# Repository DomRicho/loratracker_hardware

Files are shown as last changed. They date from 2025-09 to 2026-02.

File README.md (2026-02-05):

# LoRa Tracker HAT+

This board was developed for my engineering honours project, exploring how LoRa—a low-power, long-range wireless technology—could improve animal tracking. 
Now LoRa is already well established in this field. However, is removing the need for GNSS by localising using the LoRa packets possible? 
This could simplify devices, save battery, and reduce interference with wildlife behaviour, especially for small or sensitive species 
like wild bilbies.

The project investigates two localisation methods: **RSSI** and **Time-Difference of Arrival (TDoA)**.

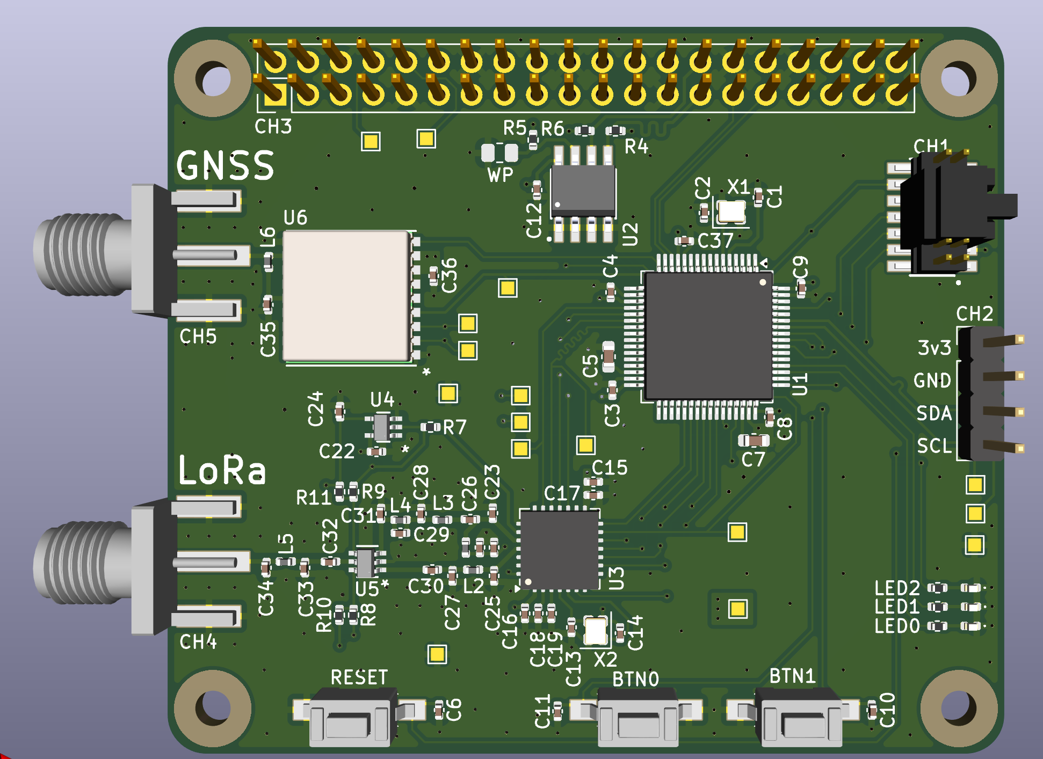
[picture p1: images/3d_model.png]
3D Model


The HAT+ is a custom Raspberry Pi board featuring an STM32H7, GNSS module, LoRa modem, and I2C environmental sensor. 
Three boards act as anchors to trilaterate LoRa packet sources. To handle packets moving at the speed of light, the
anchors are synchronised via GPS pulse-per-second signals, keeping jitter under 20 ns.

## Issues

- CADDetected on the SX1272 couldn’t reliably timestamp preambles; switched to using the **ValidHeader** flag instead.  
- DIO4 trace was cut, and DIO3 was rerouted to the STM32H7 input capture pin.  
- Standard crystals drift roughly 20 µs, translating to tens of km of error. Achieving nanosecond-level timing 
requires expensive oven-controlled crystals (~$450 for three), compared to ~$0.60 for standard ones. Lesson learned

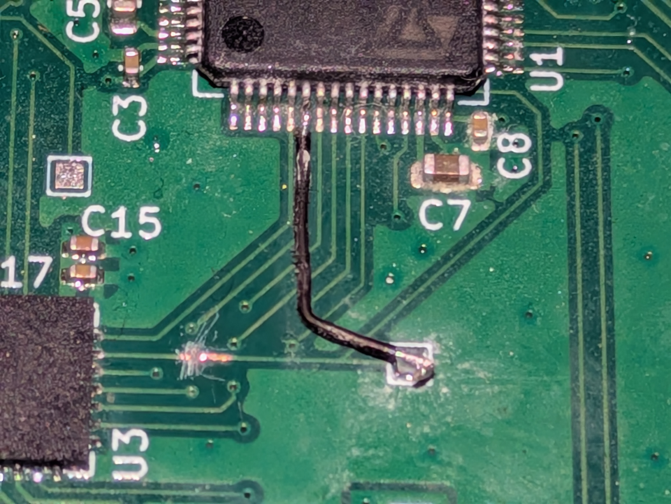
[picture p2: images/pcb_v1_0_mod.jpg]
PCB v1.0 Mod


## Future Plans
- Battery power  
- Solar charging

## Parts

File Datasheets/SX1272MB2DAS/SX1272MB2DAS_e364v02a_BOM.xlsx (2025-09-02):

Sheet: SX1272MB2DAS - BOM
 |  |  | SX1272MB2DAS - BOM |  |  | BOM # V1a
 |  |  |  |  |  | SCH # e364v02a
 |  |  | 2023-08-17 | EMr | Version e364V02a - 868MHz and 915MHz | PCB # e364v02a
RefDes | MPN | Geom | Value | Qty | Description | Manufacturer
IC
U1 | SX1272IMLTRT | TQFN-28 6x6mm | SX1272 | 1 | 860MHz to 1020MHz Low Power Long Range Transceiver | Semtech
U2 | PE4259 | SC-70-6 | - | 1 | PE4259 - 10MHz to 3GHz SPDT RF Switch | Peregrine Semi
U3 | NC7SZ04P5X | SC-70-5 | - | 1 | NC7SZ04 TinyLogic UHS Inverter | Fairchild Semi
U4 | CRCW06030000Z0EA | 0603 | 0R | 1 | Thick Film Resistor ±5%, 1/10W (No SAW filter populated) | Vishay/Dale
Resistors
R1 | CRCW04023K30JNED | 0402 | 3.3k | 1 | Thick Film Resistor ±5%, 1/16W | Vishay/Dale
R2 | CRCW04023K30JNED | 0402 | 3.3k | 1 | Thick Film Resistor ±5%, 1/16W | Vishay/Dale
R3 | CRCW06030000Z0EA | 0603 | 0R | 1 | Thick Film Resistor ±5%, 1/10W | Vishay/Dale
R4 | EXB-N8V101JX | EXB28V | 100R | 1 | SMD Resistor Array Resistors (4x), ±5%, 31mW | Panasonic - ECG
R5 | EXB-N8V101JX | EXB28V | 100R | 1 | SMD Resistor Array Resistors (4x), ±5%, 31mW | Panasonic - ECG
R6 | CRCW06030000Z0EA | 0603 | 0R | 1 | Thick Film Resistor ±5%, 1/10W | Vishay/Dale
R7 | CRCW0402100RJNED | 0402 | 100R | 1 | Thick Film Resistor ±5%, 1/16W | Vishay/Dale
R11 | CRCW04021K00JNED | 0402 | 1k | 1 | Thick Film Resistor ±5%, 1/16W | Vishay/Dale
R14 | CRCW0402100RJNED | 0402 | 100R | 1 | Thick Film Resistor ±5%, 1/16W | Vishay/Dale
Capacitors
C1 | GJM1555C1H150JB01D | 0402 | 15pF | 1 | Multilayer ceramic capacitors C0G ±5%, 50V | Murata
C2 | GJM1555C1H150JB01D | 0402 | 15pF | 1 | Multilayer ceramic capacitors C0G ±5%, 50V | Murata
C3 | GRM155R71H104KE14D | 0402 | 100nF | 1 | Multilayer ceramic capacitors X7R ±10%, 50V | Murata
C4 | GRM155R71H104KE14D | 0402 | 100nF | 1 | Multilayer ceramic capacitors X7R ±10%, 50V | Murata
C5 | GRM155R71H104KE14D | 0402 | 100nF | 1 | Multilayer ceramic capacitors X7R ±10%, 50V | Murata
C6 | GRM155R61C105KA12D | 0402 (0603) | 1uF | 1 | Multilayer ceramic capacitors X5R ±10%, 16V | Murata
C7 | GRM155R71H103KA88D | 0402 | 10nF | 1 | Multilayer ceramic capacitors X7R ±10%, 50V | Murata
C8 | GJM1555C1H470JB01D | 0402 | 47pF | 1 | Multilayer ceramic capacitors C0G ±5%, 50V | Murata
C9 | GJM1555C1H330JB01D | 0402 | 33pF | 1 | Multilayer ceramic capacitors C0G ±5%, 50V | Murata
C10 | GJM1555C1H1R5BB01D | 0402 | 1.5pF | 1 | Multilayer ceramic capacitors C0G ±0.1pF, 50V | Murata
C11 | GJM1555C1H4R7CB01D | 0402 | 4.7pF | 1 | Multilayer ceramic capacitors C0G ±0.25pF, 50V | Murata
C12 | GJM1555C1H1R2BB01D | 0402 | 1.2pF | 1 | Multilayer ceramic capacitors C0G ±0.1pF, 50V | Murata
C13 | GJM1555C1H1R8BB01D | 0402 | 1.8pF | 1 | Multilayer ceramic capacitors C0G ±0.1pF, 50V | Murata
C15 | GJM1555C1H3R3BB01D | 0402 | 3.3pF | 1 | Multilayer ceramic capacitors C0G ±0.1pF, 50V | Murata
C16 | GJM1555C1H470JB01D | 0402 | 47pF | 1 | Multilayer ceramic capacitors C0G ±5%, 50V | Murata
C17 | GRM155R72A102KA01D | 0402 | 1nF | 1 | Multilayer ceramic capacitors X7R ±10%, 100V | Murata
C18 | GJM1555C1H470JB01D | 0402 | 47pF | 1 | Multilayer ceramic capacitors C0G ±5%, 50V | Murata
C21 | GRM155R71H104KE14D | 0402 | 100nF | 1 | Multilayer ceramic capacitors X7R ±10%, 50V | Murata
C22 | GRM155R72A102KA01D | 0402 | 1nF | 1 | Multilayer ceramic capacitors X7R ±10%, 100V | Murata
C23 | GRM188R60J226MEA0D | 0603 (0805) | 22uF | 1 | Multilayer ceramic capacitors X5R ±20%, 6.3V | Murata
C24 | GRM155R61C105KA12D | 0402 (0603) | 1uF | 1 | Multilayer ceramic capacitors X5R ±10%, 16V | Murata
C25 | GRM155R61C105KA12D | 0402 (0603) | 1uF | 1 | Multilayer ceramic capacitors X5R ±10%, 16V | Murata
C26 | GRM155R71H104KE14D | 0402 | 100nF | 1 | Multilayer ceramic capacitors X7R ±10%, 50V | Murata
C27 | GRM155R71H104KE14D | 0402 | 100nF | 1 | Multilayer ceramic capacitors X7R ±10%, 50V | Murata
Inductors & Ferrites
L1 | LQW15AN33NJ00D | 0402 | 33nH | 1 | Wirewound Inductor ±5% | Murata
L3 | LQG15HS10NJ02D | 0402 | 10nH | 1 | Multilayer Inductor ±5% | Murata
L4 | LQG15HS6N2S02D | 0402 | 6.2nH | 1 | Multilayer Inductor ±0.3nH | Murata
L5 | LQG15HS10NJ02D | 0402 | 10nH | 1 | Multilayer Inductor ±5% | Murata
L6 | CRCW04020000Z0ED | 0402 | 0R | 1 | Thick Film Resistor ±5%, 1/16W | Vishay/Dale
Crystal (or other referenced vendors)
Q1 | EXS00A-CS06465 | NX2016SA 2.0x1.6mm | 32.000MHz | 1 | Crystal unit NDK; Tol. ±10ppm, Cload=10pF, G-Senstivity=2ppb/G max | NDK
or | FTR5123-B0 | QESM09 2.0x1.6mm | 32.000MHz | - | Crystal unit Rakon; Tol. ±10ppm, Cload=10pF, G-Senstivity=2ppb/G max | Rakon
Connectors and others (or P/N equivalent)
ANT | 142-0711-821 | SMA End Launch | 50 Ohms | 1 | SMA End launch jack receptacle for PCB mount | Emerson Network Power
J1 | 68000-108HLF | Header 1x8 | 8 pins | 1 | 8 Pins - Through hole single row male connector, Bottom side | FCI
J2 | 68000-110HLF | Header 1x10 | 10 pins | 1 | 10 Pins - Through hole single row male connector, Bottom side | FCI
J3 | 68000-108HLF | Header 1x8 | 8 pins | 1 | 8 Pins - Through hole single row male connector, Bottom side | FCI
J4 | 68000-106HLF | Header 1x6 | 6 pins | 1 | 6 Pins - Through hole single row male connector, Bottom side | FCI
ANA_A1 | 1125S-4P | Header 1x4 | 4 pins | 1 | 4 Pins - 2mm pitch - Through hole single row male header connector with lock, Top side | Shenzhen NS-Tech
ANA_A3 | 1125S-4P | Header 1x4 | 4 pins | 1 | 4 Pins - 2mm pitch - Through hole single row male header connector with lock, Top side | Shenzhen NS-Tech
DIO_D6 | 1125S-4P | Header 1x4 | 4 pins | 1 | 4 Pins - 2mm pitch - Through hole single row male header connector with lock, Top side | Shenzhen NS-Tech
DIO_D8 | 1125S-4P | Header 1x4 | 4 pins | 1 | 4 Pins - 2mm pitch - Through hole single row male header connector with lock, Top side | Shenzhen NS-Tech
I2C | 1125S-4P | Header 1x4 | 4 pins | 1 | 4 Pins - 2mm pitch - Through hole single row male header connector with lock, Top side | Shenzhen NS-Tech
UART | 1125S-4P | Header 1x4 | 4 pins | 1 | 4 Pins - 2mm pitch - Through hole single row male header connector with lock, Top side | Shenzhen NS-Tech
Additional or optional components
- | BMIS-205-F | Shield | - | 0 | Standard Surface Mount Shield in two parts with BMIS-205-C cover | Laird Technologies
Remarks: components not listed in the BOM or 0 quantity, are not populated on the module.
It is recommended to use Semtech TVS diode model RClamp2451ZA placed close to the antenna connectors, to protect sensitive RF ports from damage or latch-up due to ESD, EFT, and EOS.
Murata GRM15 Multilayer ceramic capacitors series with values ≤ 47pF were replaced from previous BOM to new GJM15 series, as replacement with same capacitance value, voltage rating and tolerance.
GRM15 series ≤ 47pF are not recommended for new designs according to Murata.

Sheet: Release
 |  | SX1272MB2DAS - BOM |  |  |  | BOM # V1a
 |  |  |  |  |  | SCH # e364v02a
 |  | 2023-08-17 | EMr | Version e364v02a |  | PCB # e364v02a
Release history
Version | Change notes |  |  |  | By
pcb_e364V01a | BOM based on SX1272MB1DAS V1a + added Grove sensors - 14.01.16 |  |  |  | EMr
 | Modifed 32.0MHz crystal 2.0x1.6mm footprint for Q1 |  |  |  | EMr
 | Modifed C2=15pF to center RF frequency using NX2016SA NDK Crystal - 05.02.16 |  |  |  | EMr
pcb_e364V02a | Modied R5 & R13 - changed silkscreen labels |  |  |  | EMr
 | Added BMIS-205-F reference for RF shield in the BOM - not populated - 13.04.16 |  |  |  | EMr
 | Change SX1272MB2DAS Part number on BOM - 27.05.16 |  |  |  | EMr
 | Updated Part Numbers for obsolete capacitors type (value < 100pF) - no change on components values |  |  |  | EMr - 18.10.22
 | Updated Crystal P/N and Update GJM15 Capacitors type |  |  |  | 2023-08-15

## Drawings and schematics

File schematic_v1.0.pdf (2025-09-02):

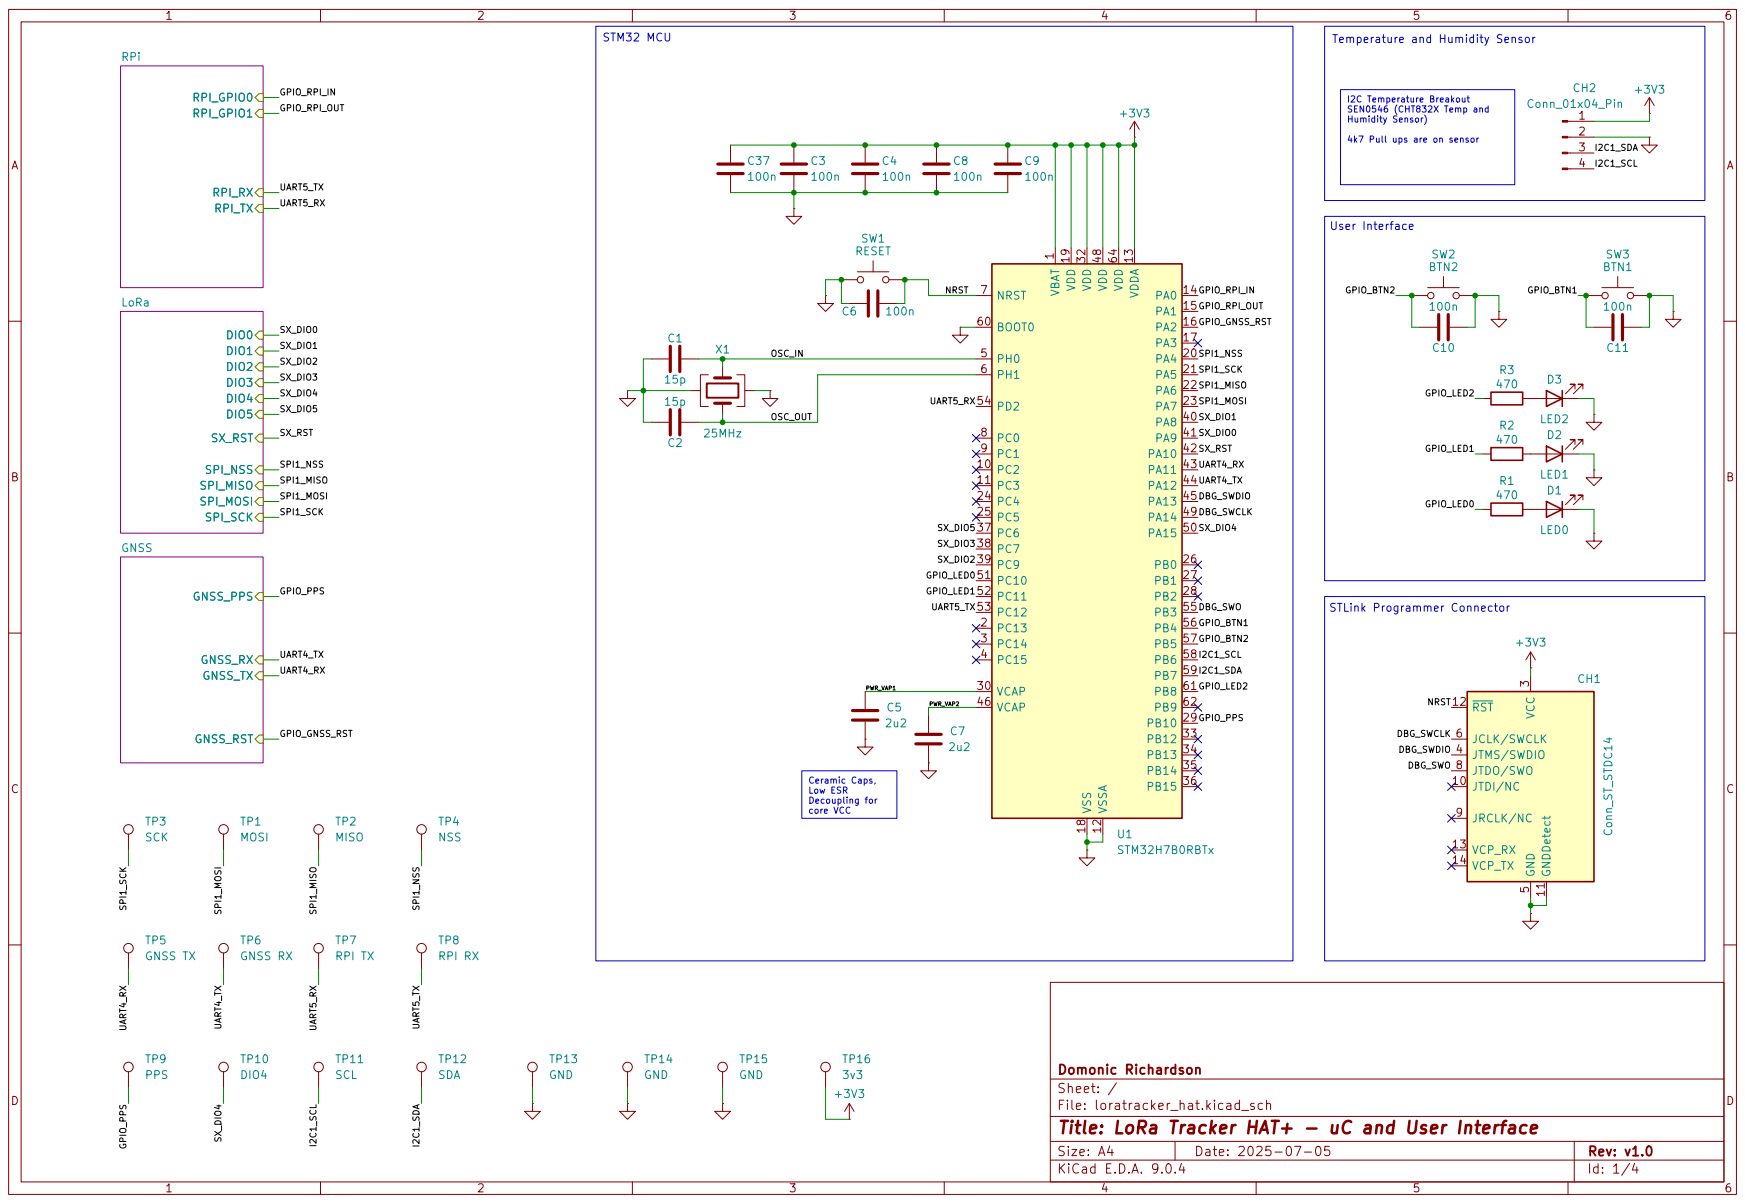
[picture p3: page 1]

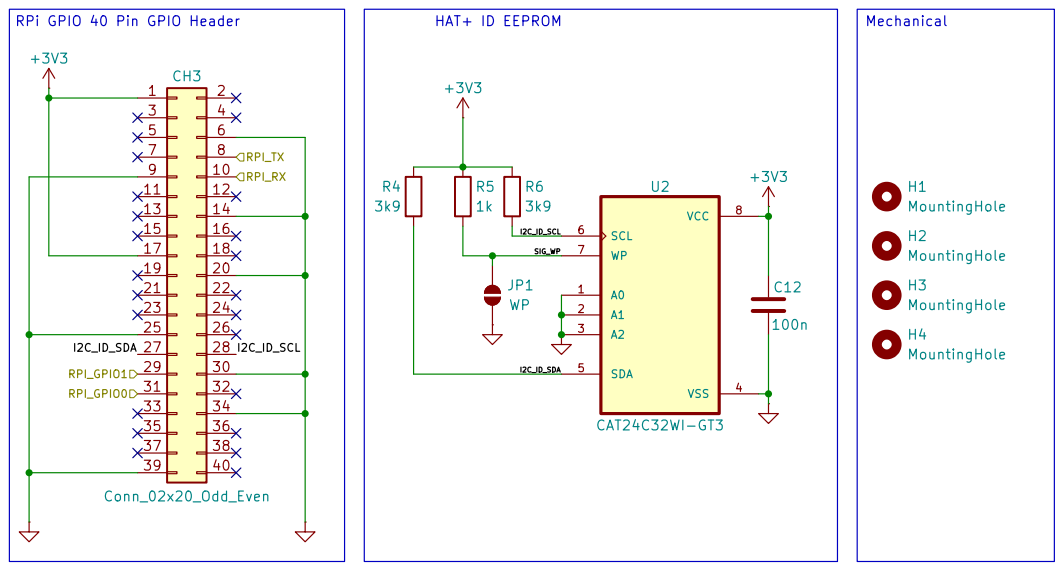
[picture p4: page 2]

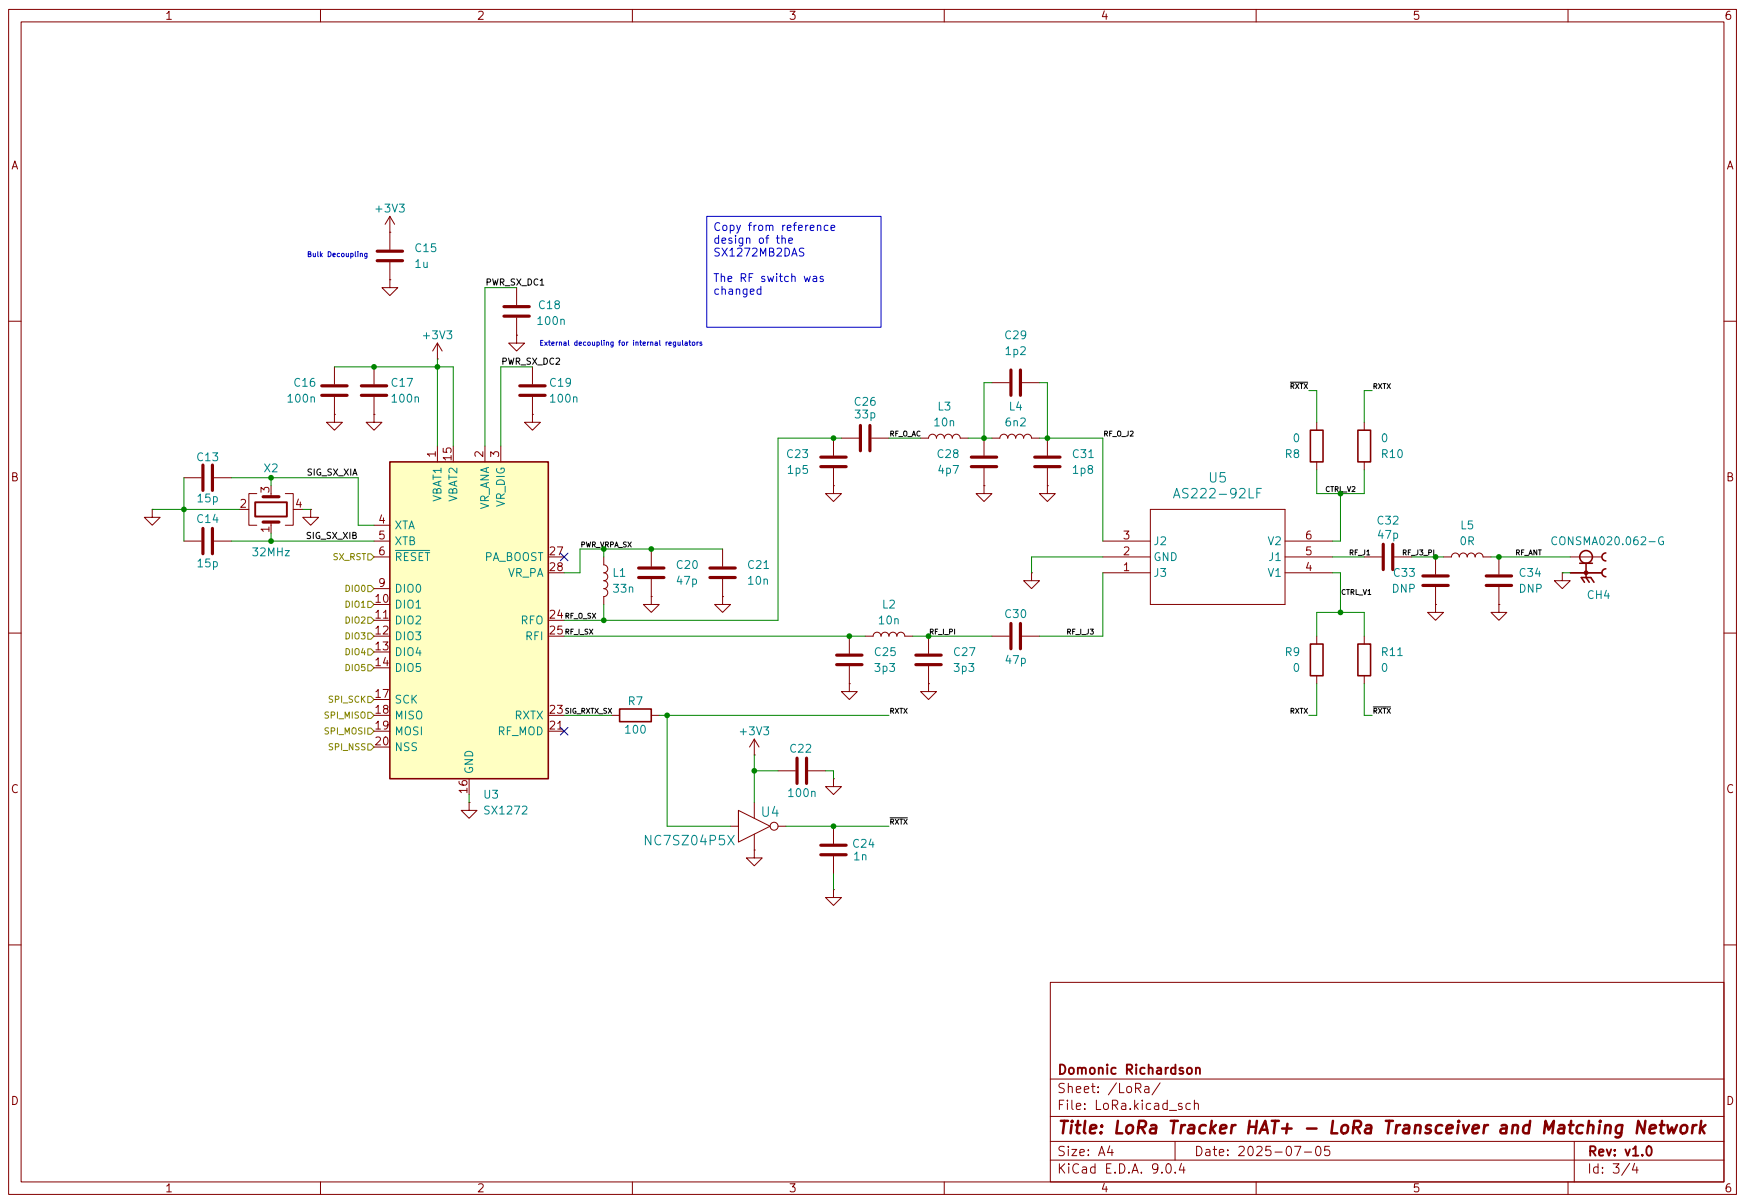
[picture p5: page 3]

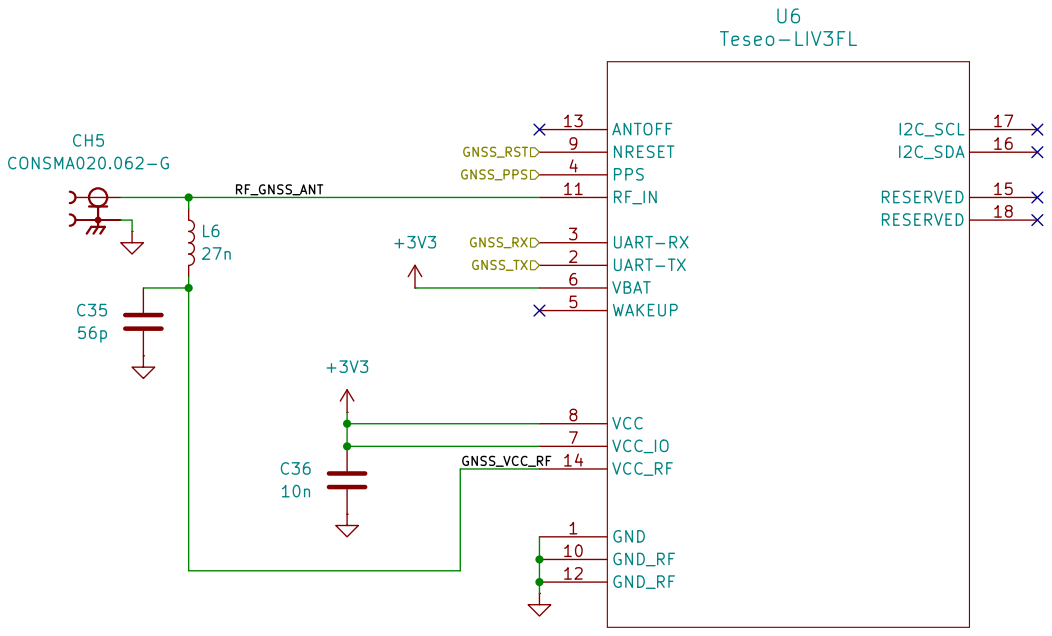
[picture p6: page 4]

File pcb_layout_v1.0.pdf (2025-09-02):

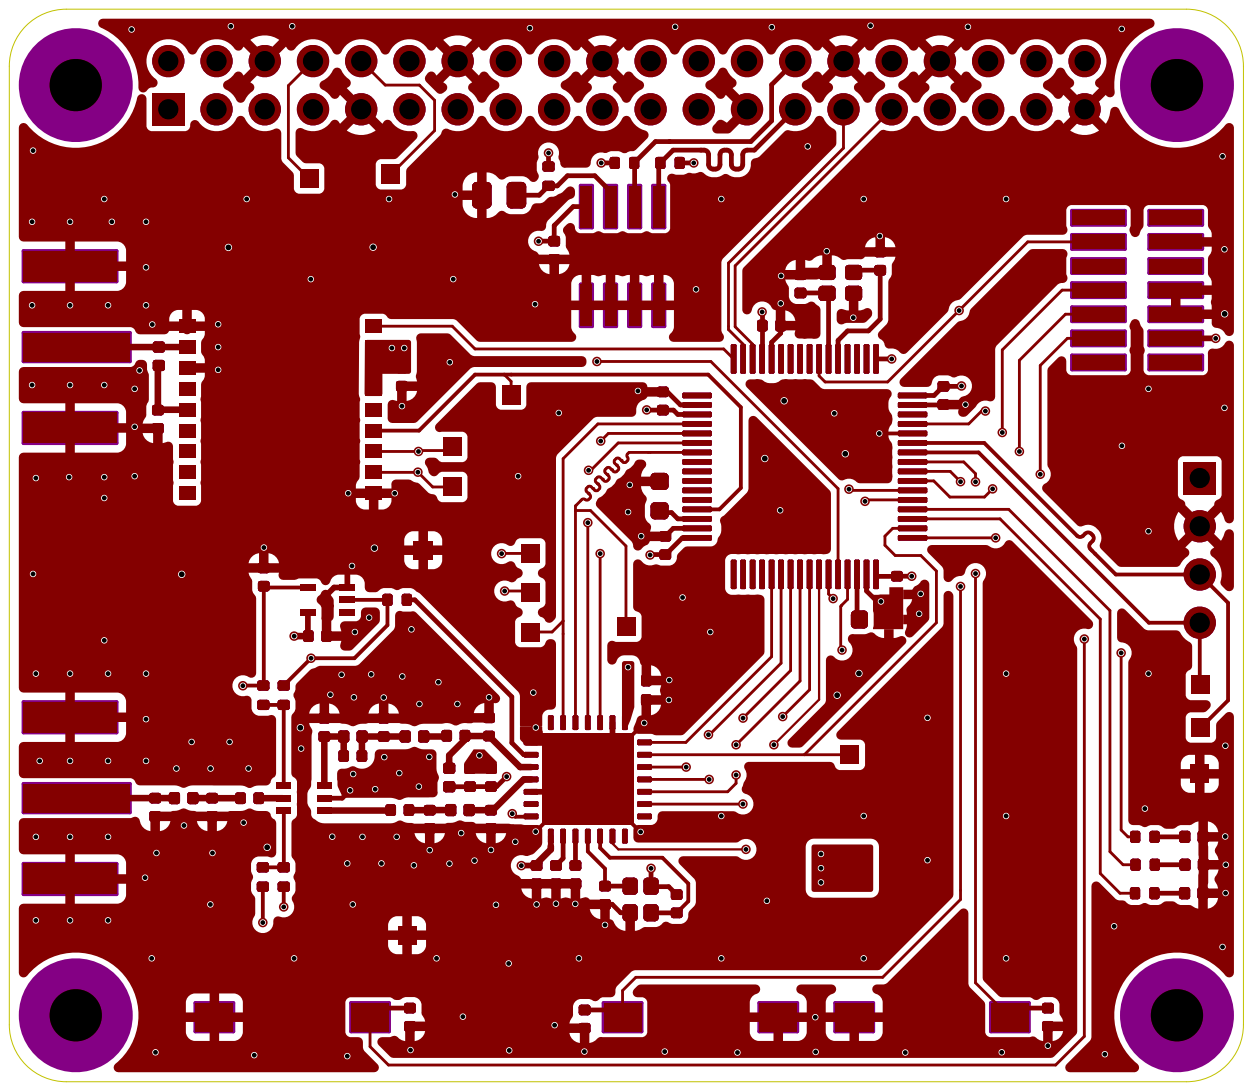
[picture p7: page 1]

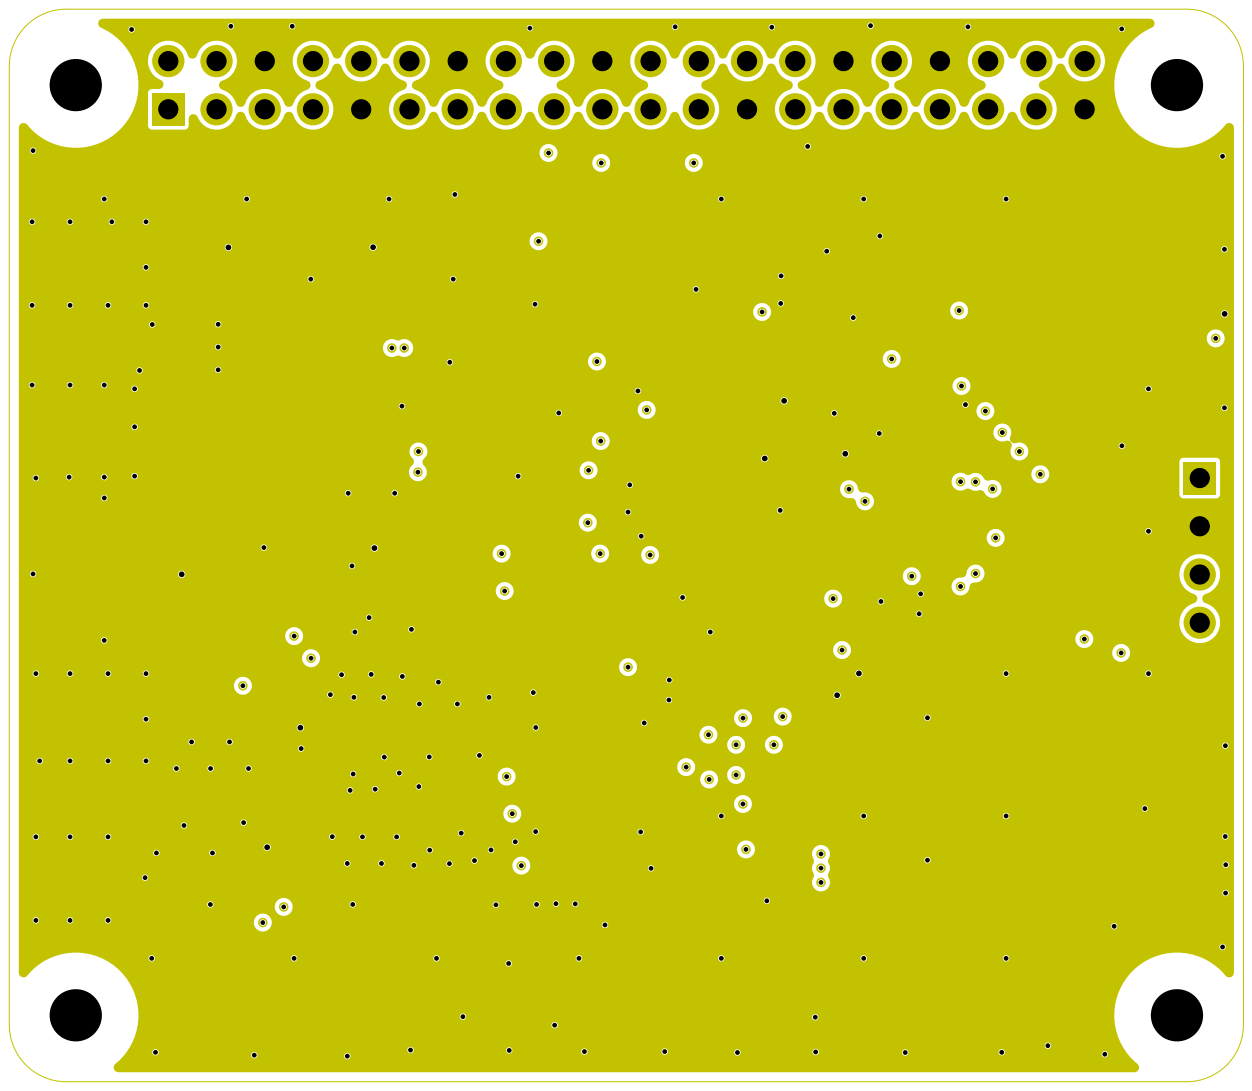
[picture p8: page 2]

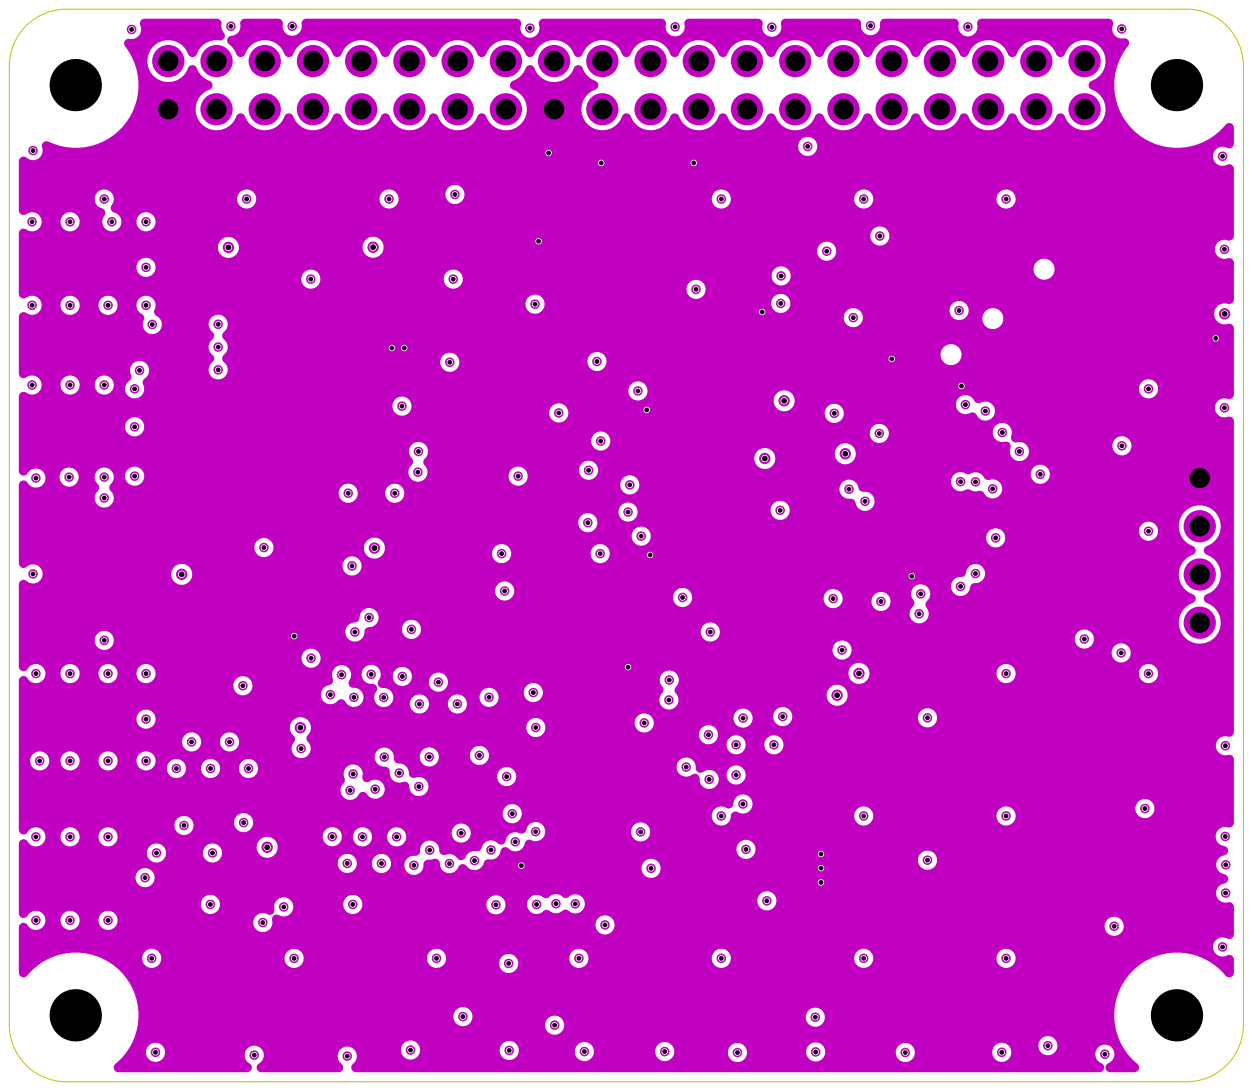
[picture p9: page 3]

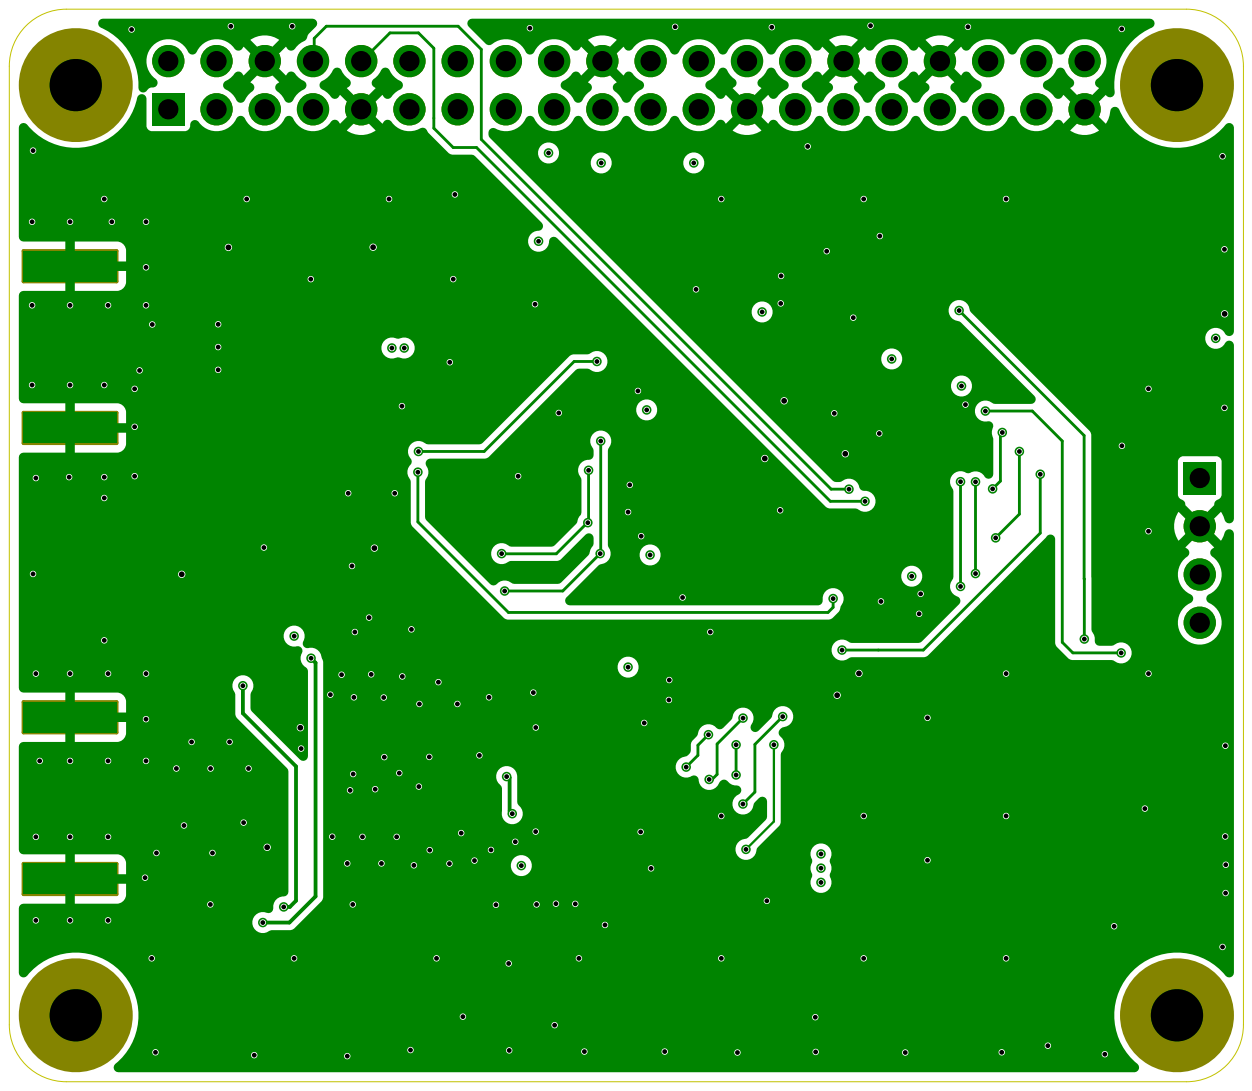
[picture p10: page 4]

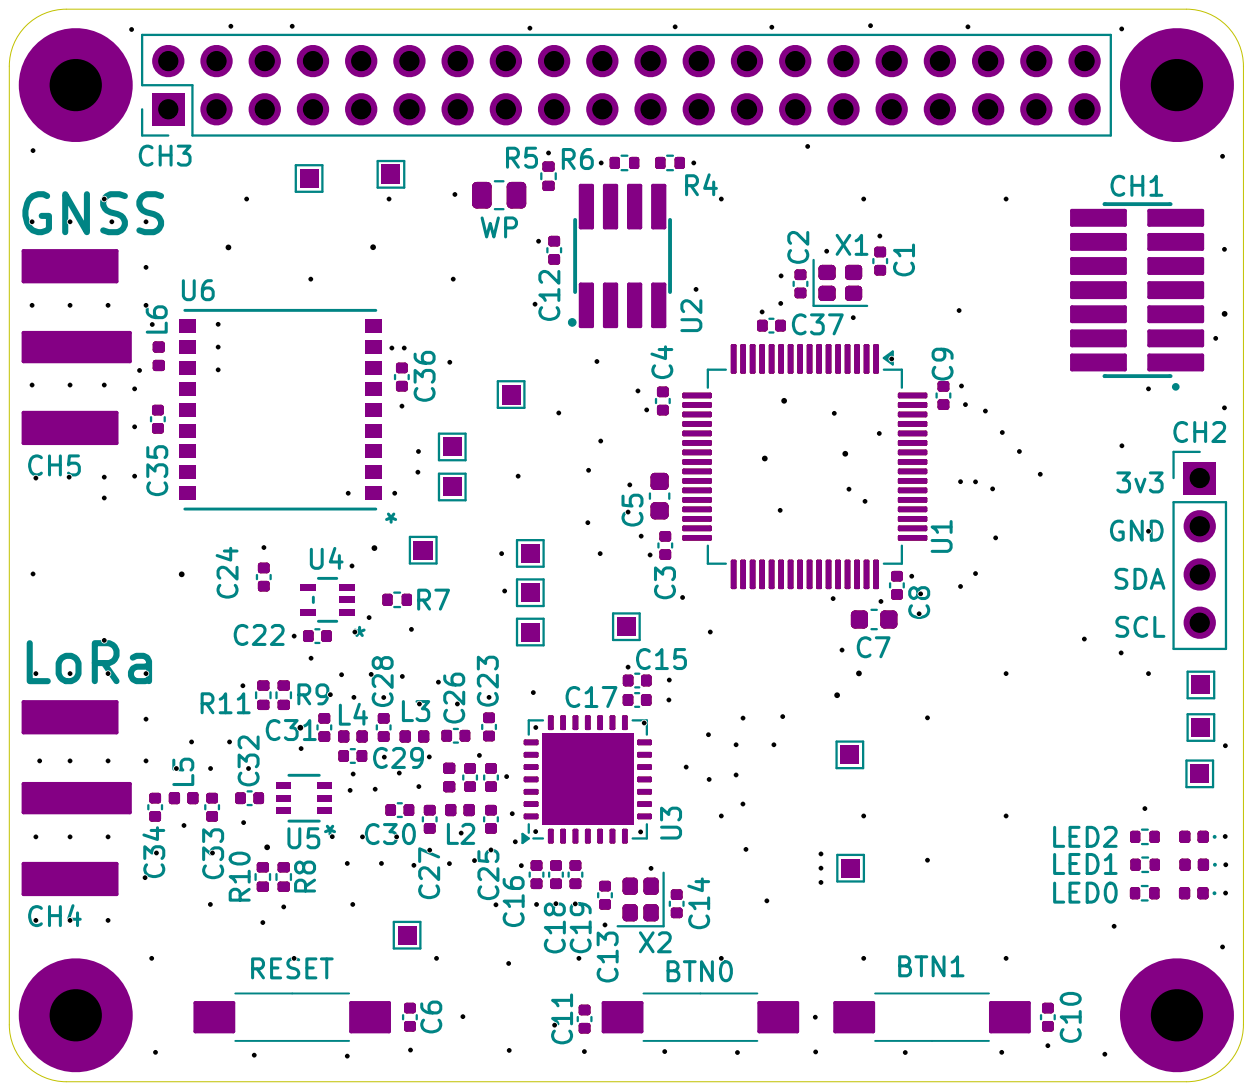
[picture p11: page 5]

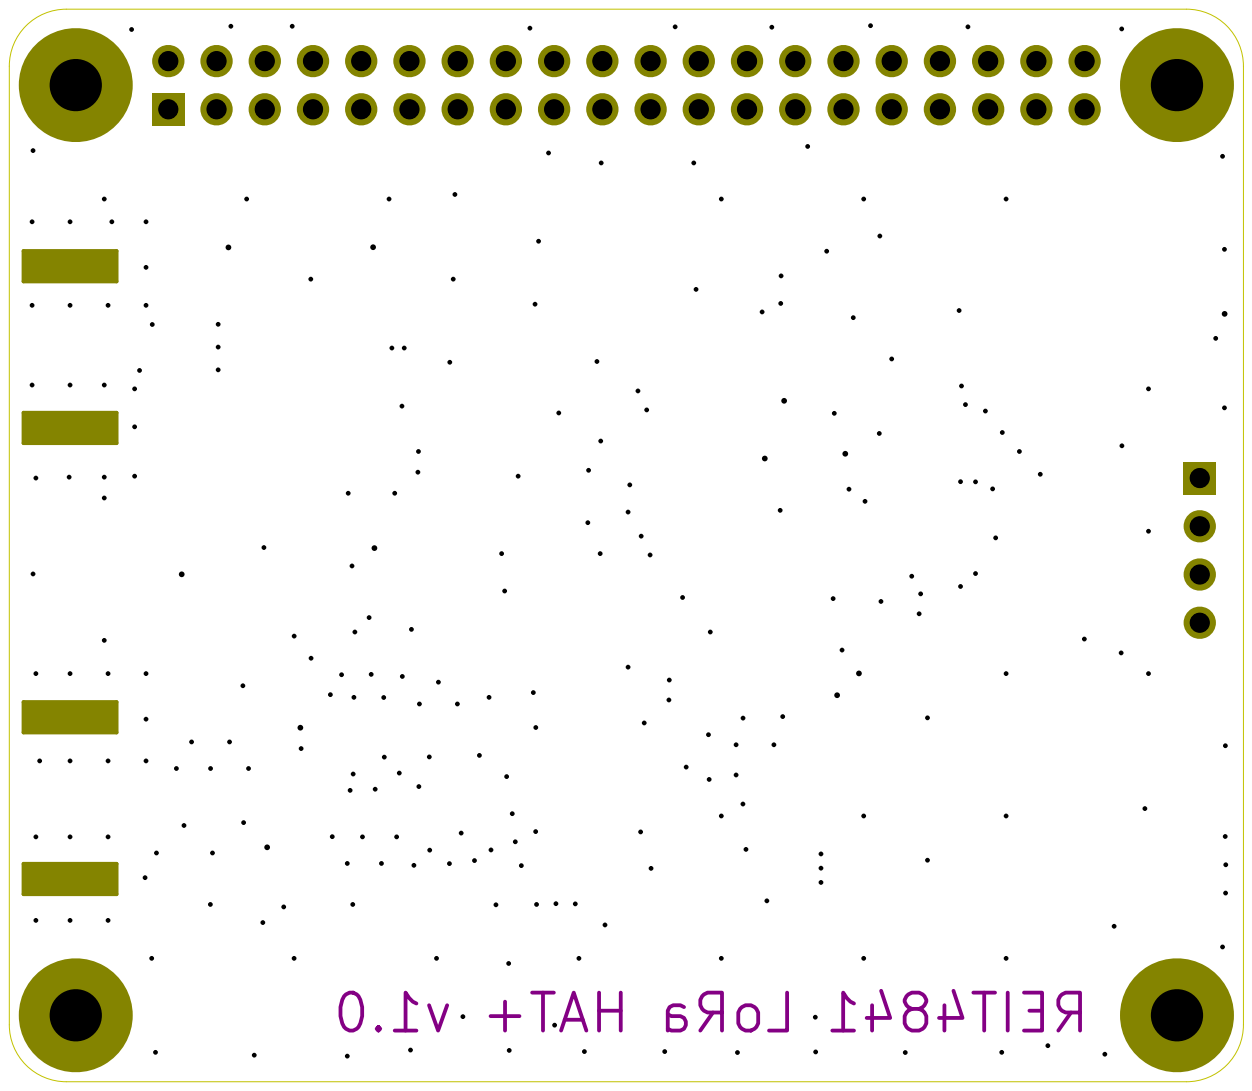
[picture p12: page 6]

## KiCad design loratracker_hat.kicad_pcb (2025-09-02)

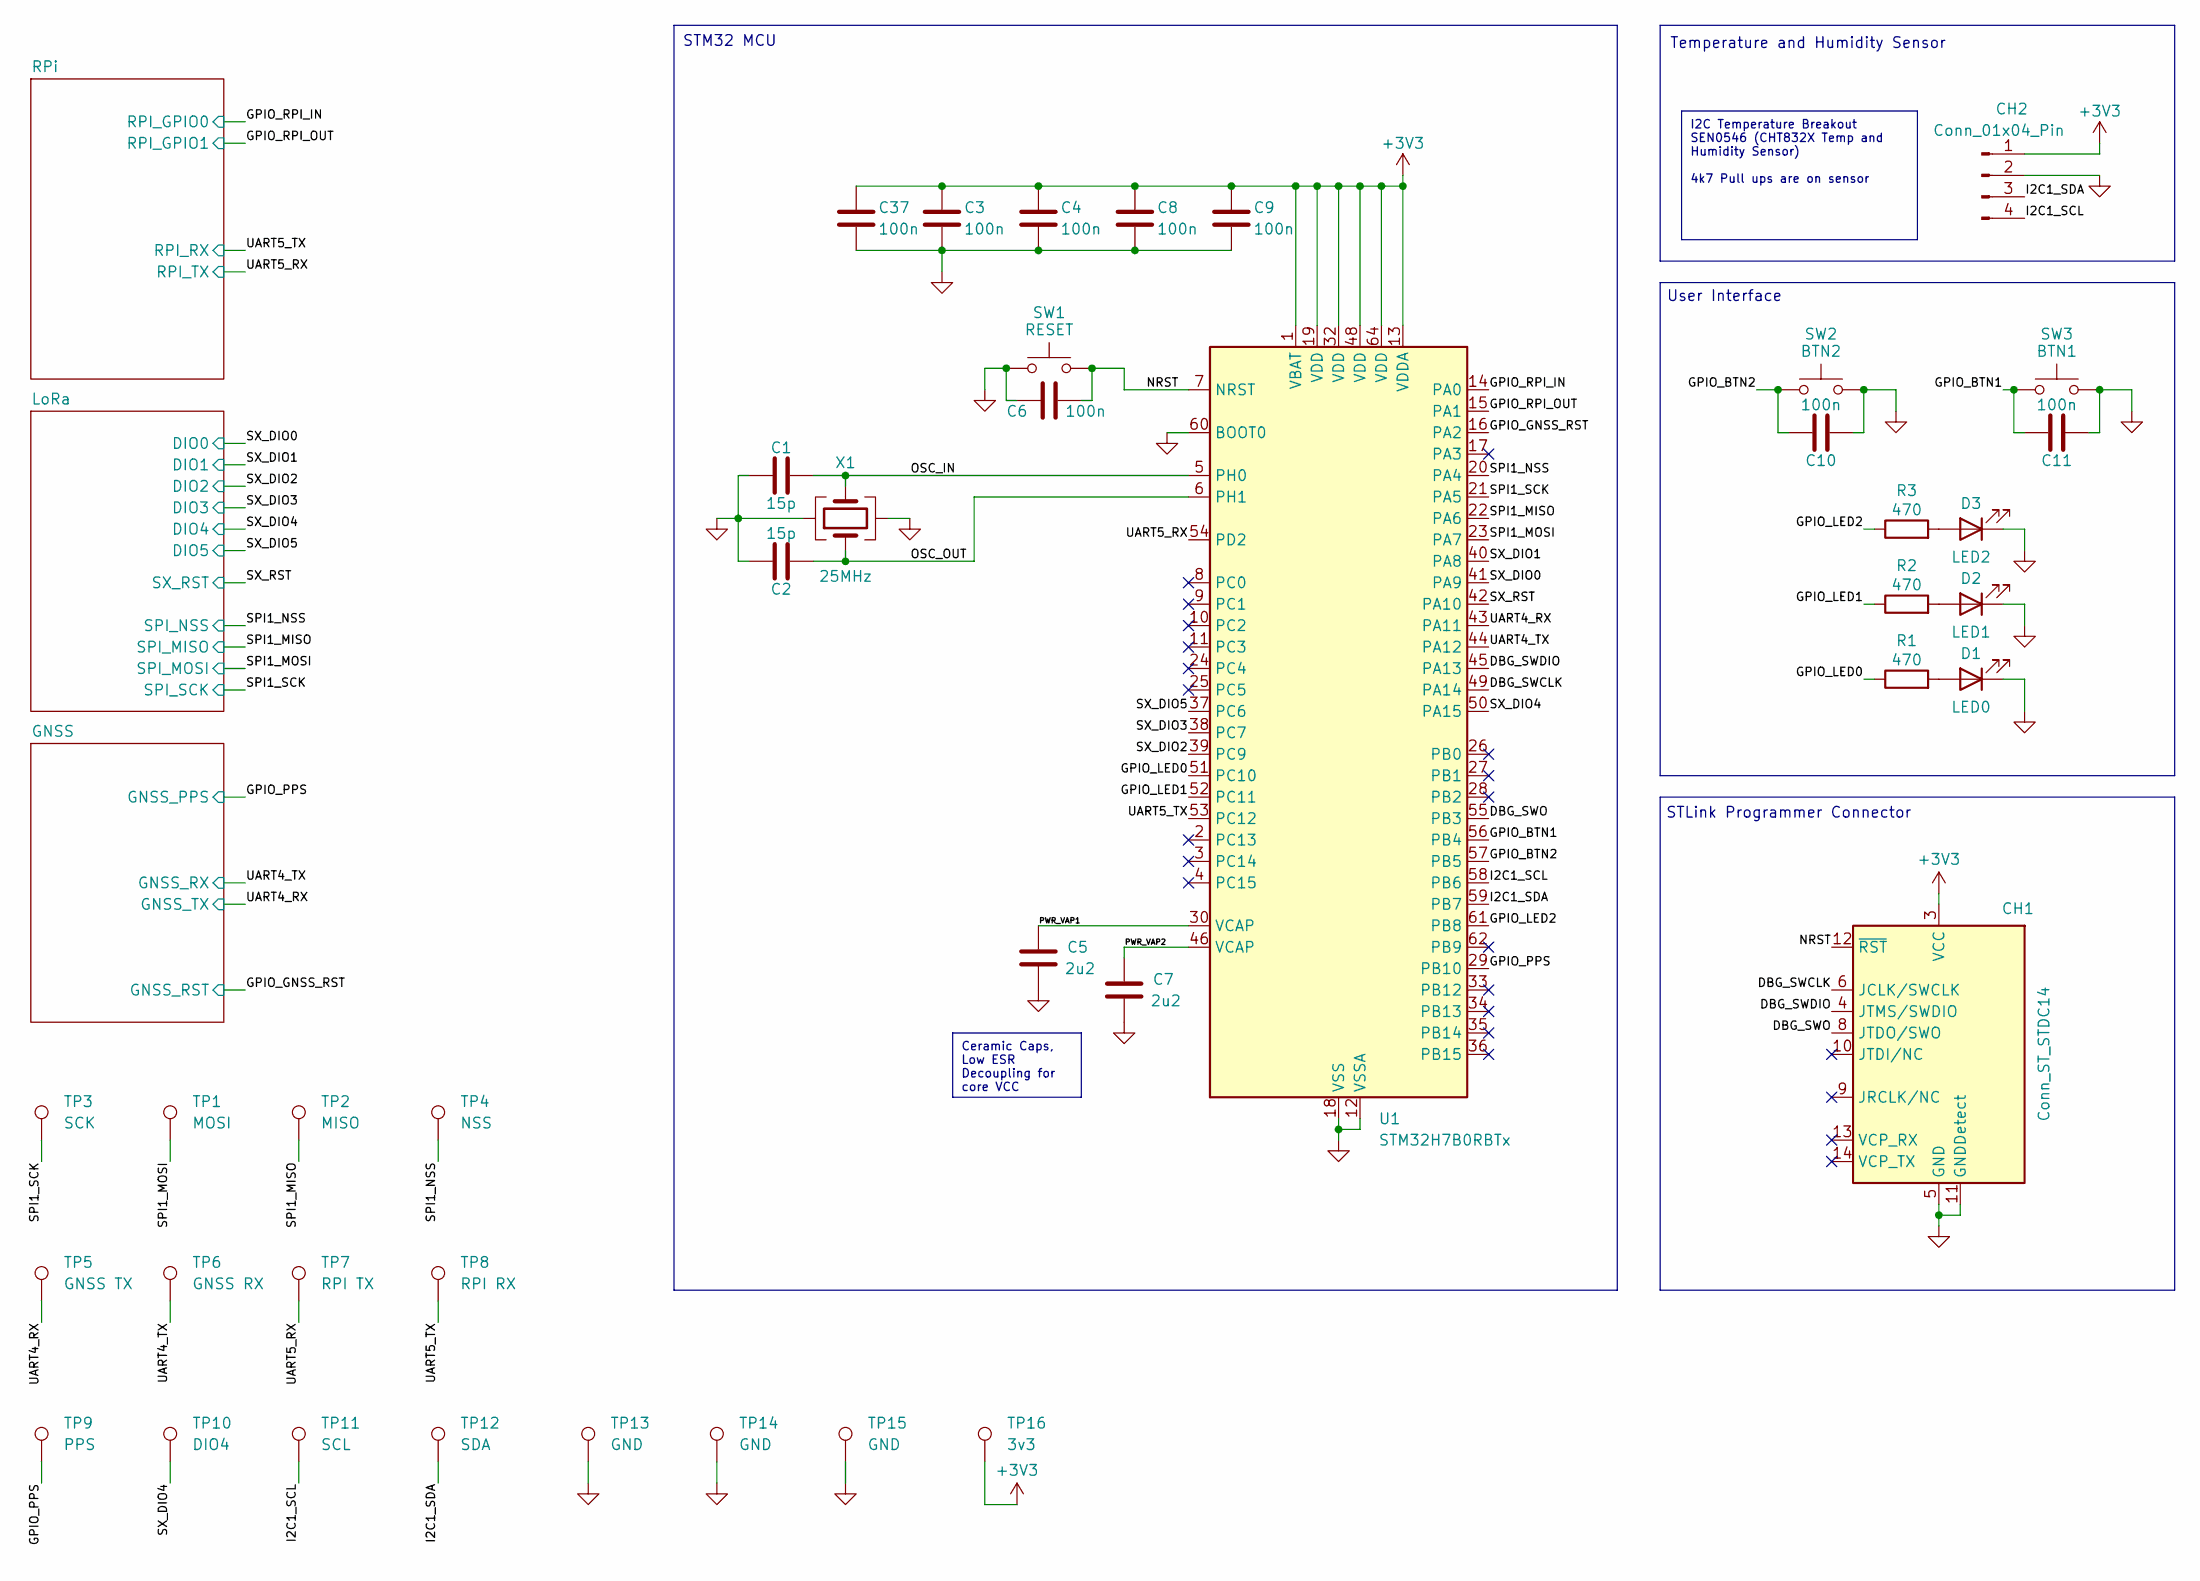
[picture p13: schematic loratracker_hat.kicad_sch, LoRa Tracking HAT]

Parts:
C1, C2: 15p; C_0402_1005Metric
C3, C4, C6, C8, C9, C10, C11, C37: 100n; C_0402_1005Metric
C5, C7: 2u2; C_0603_1608Metric
CH1: Conn_ST_STDC14; SAMTEC_FTSH-107-01-L-DV-A-TR
CH2: Conn_01x04_Pin; PinHeader_1x04_P2.54mm_Vertical
D1: LED0; LED_0402_1005Metric
D2: LED1; LED_0402_1005Metric
D3: LED2; LED_0402_1005Metric
R1, R2, R3: 470; R_0402_1005Metric
SW1: RESET; PTS636SM43SMTR
SW2: BTN2; PTS636SM43SMTR
SW3: BTN1; PTS636SM43SMTR
TP1: MOSI; TestPoint_Pad_1.0x1.0mm
TP2: MISO; TestPoint_Pad_1.0x1.0mm
TP3: SCK; TestPoint_Pad_1.0x1.0mm
TP4: NSS; TestPoint_Pad_1.0x1.0mm
TP5: GNSS TX; TestPoint_Pad_1.0x1.0mm
TP6: GNSS RX; TestPoint_Pad_1.0x1.0mm
TP7: RPI TX; TestPoint_Pad_1.0x1.0mm
TP8: RPI RX; TestPoint_Pad_1.0x1.0mm
TP9: PPS; TestPoint_Pad_1.0x1.0mm
TP10: DIO4; TestPoint_Pad_1.0x1.0mm
TP11: SCL; TestPoint_Pad_1.0x1.0mm
TP12: SDA; TestPoint_Pad_1.0x1.0mm
TP13, TP14, TP15: GND; TestPoint_Pad_1.0x1.0mm
TP16: 3v3; TestPoint_Pad_1.0x1.0mm
U1: STM32H7B0RBTx; LQFP-64_10x10mm_P0.5mm
X1: 25MHz; Crystal_SMD_2016-4Pin_2.0x1.6mm

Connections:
+3V3: C3.1, C4.1, C8.1, C9.1, C37.1, CH1.3 (VCC), CH2.1, TP16.1, U1.1 (VBAT), U1.13 (VDDA), U1.19 (VDD), U1.32 (VDD), U1.48 (VDD), U1.64 (VDD); also elsewhere on the board
/DBG_SWCLK: CH1.6 (JCLK/SWCLK), U1.49 (PA14)
/DBG_SWDIO: CH1.4 (JTMS/SWDIO), U1.45 (PA13)
/DBG_SWO: CH1.8 (JTDO/SWO), U1.55 (PB3)
/GPIO_BTN1: C11.2, SW3.1, U1.56 (PB4)
/GPIO_BTN2: C10.2, SW2.1, U1.57 (PB5)
/GPIO_GNSS_RST: U1.16 (PA2); also elsewhere on the board
/GPIO_LED0: R1.1, U1.51 (PC10)
/GPIO_LED1: R2.1, U1.52 (PC11)
/GPIO_LED2: R3.1, U1.61 (PB8)
/GPIO_PPS: TP9.1, U1.29 (PB10); also elsewhere on the board
/GPIO_RPI_IN: U1.14 (PA0); also elsewhere on the board
/GPIO_RPI_OUT: U1.15 (PA1); also elsewhere on the board
/I2C1_SCL: CH2.4, TP11.1, U1.58 (PB6)
/I2C1_SDA: CH2.3, TP12.1, U1.59 (PB7)
/NRST: C6.1, CH1.12 (~RST), SW1.2, U1.7 (NRST)
/OSC_IN: C1.2, U1.5 (PH0), X1.3
/OSC_OUT: C2.1, U1.6 (PH1), X1.1
/PWR_VAP1: C5.1, U1.30 (VCAP)
/PWR_VAP2: C7.1, U1.46 (VCAP)
/SPI1_MISO: TP2.1, U1.22 (PA6); also elsewhere on the board
/SPI1_MOSI: TP1.1, U1.23 (PA7); also elsewhere on the board
/SPI1_NSS: TP4.1, U1.20 (PA4); also elsewhere on the board
/SPI1_SCK: TP3.1, U1.21 (PA5); also elsewhere on the board
/SX_DIO0: U1.41 (PA9); also elsewhere on the board
/SX_DIO1: U1.40 (PA8); also elsewhere on the board
/SX_DIO2: U1.39 (PC9); also elsewhere on the board
/SX_DIO3: U1.38 (PC7); also elsewhere on the board
/SX_DIO4: TP10.1, U1.50 (PA15); also elsewhere on the board
/SX_DIO5: U1.37 (PC6); also elsewhere on the board
/SX_RST: U1.42 (PA10); also elsewhere on the board
/UART4_RX: TP5.1, U1.43 (PA11); also elsewhere on the board
/UART4_TX: TP6.1, U1.44 (PA12); also elsewhere on the board
/UART5_RX: TP7.1, U1.54 (PD2); also elsewhere on the board
/UART5_TX: TP8.1, U1.53 (PC12); also elsewhere on the board
GND: C1.1, C2.2, C3.2, C4.2, C5.2, C6.2, C7.2, C8.2, C9.2, C10.1, C11.1, C37.2, CH1.5 (GND), CH1.7 (GND), CH1.11 (GNDDetect), CH2.2, D1.1 (K), D2.1 (K), D3.1 (K), SW1.1, SW2.2, SW3.2, TP13.1, TP14.1, TP15.1, U1.12 (VSSA), U1.18 (VSS), U1.31 (VSS), U1.47 (VSS), U1.60 (BOOT0), U1.63 (VSS), X1.2, X1.4; also elsewhere on the board
unnamed: D1.2 (A), R1.2
unnamed: D2.2 (A), R2.2
unnamed: D3.2 (A), R3.2

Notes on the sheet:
STLink Programmer Connector
Temperature and Humidity Sensor
STM32 MCU
User Interface
I2C Temperature Breakout SEN0546 (CHT832X Temp and Humidity Sensor) 4k7 Pull ups are on sensor
Ceramic Caps, Low ESR Decoupling for core VCC

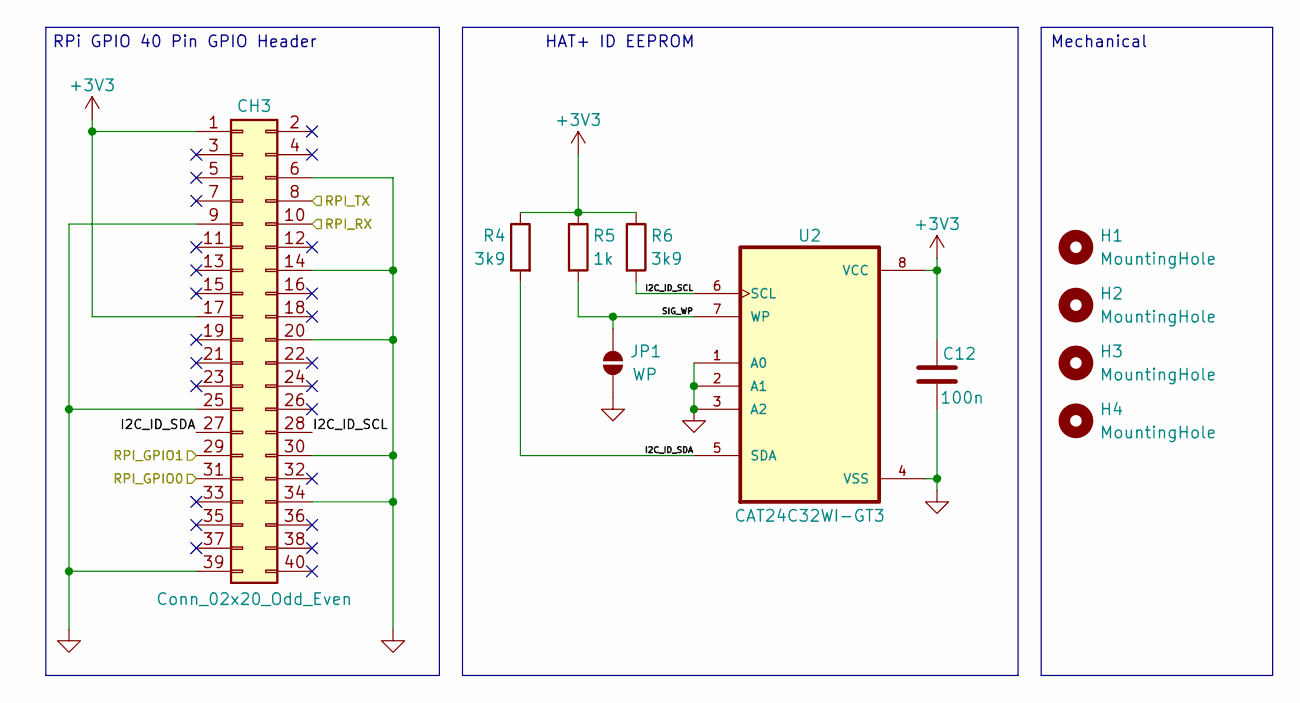
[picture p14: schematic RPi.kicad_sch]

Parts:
C12: 100n; C_0402_1005Metric
CH3: Conn_02x20_Odd_Even; PinHeader_2x20_P2.54mm_Vertical
H1, H2, H3, H4: MountingHole; RPi_mounting_holes
JP1: WP; R_0805_2012Metric
R4, R6: 3k9; R_0402_1005Metric
R5: 1k; R_0402_1005Metric
U2: CAT24C32WI-GT3; SOIC127P600X175-8N

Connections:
+3V3: C12.1, CH3.1, CH3.17, R4.1, R5.1, R6.1, U2.8 (VCC); also elsewhere on the board
/GPIO_RPI_IN: CH3.31; also elsewhere on the board
/GPIO_RPI_OUT: CH3.29; also elsewhere on the board
/RPi/I2C_ID_SCL: CH3.28, R6.2, U2.6 (SCL)
/RPi/I2C_ID_SDA: CH3.27, R4.2, U2.5 (SDA)
/RPi/SIG_WP: JP1.2 (B), R5.2, U2.7 (WP)
/UART5_RX: CH3.8; also elsewhere on the board
/UART5_TX: CH3.10; also elsewhere on the board
GND: C12.2, CH3.6, CH3.9, CH3.14, CH3.20, CH3.25, CH3.30, CH3.34, CH3.39, JP1.1 (A), U2.1 (A0), U2.2 (A1), U2.3 (A2), U2.4 (VSS); also elsewhere on the board

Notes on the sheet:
RPi GPIO 40 Pin GPIO Header
HAT+ ID EEPROM
Mechanical

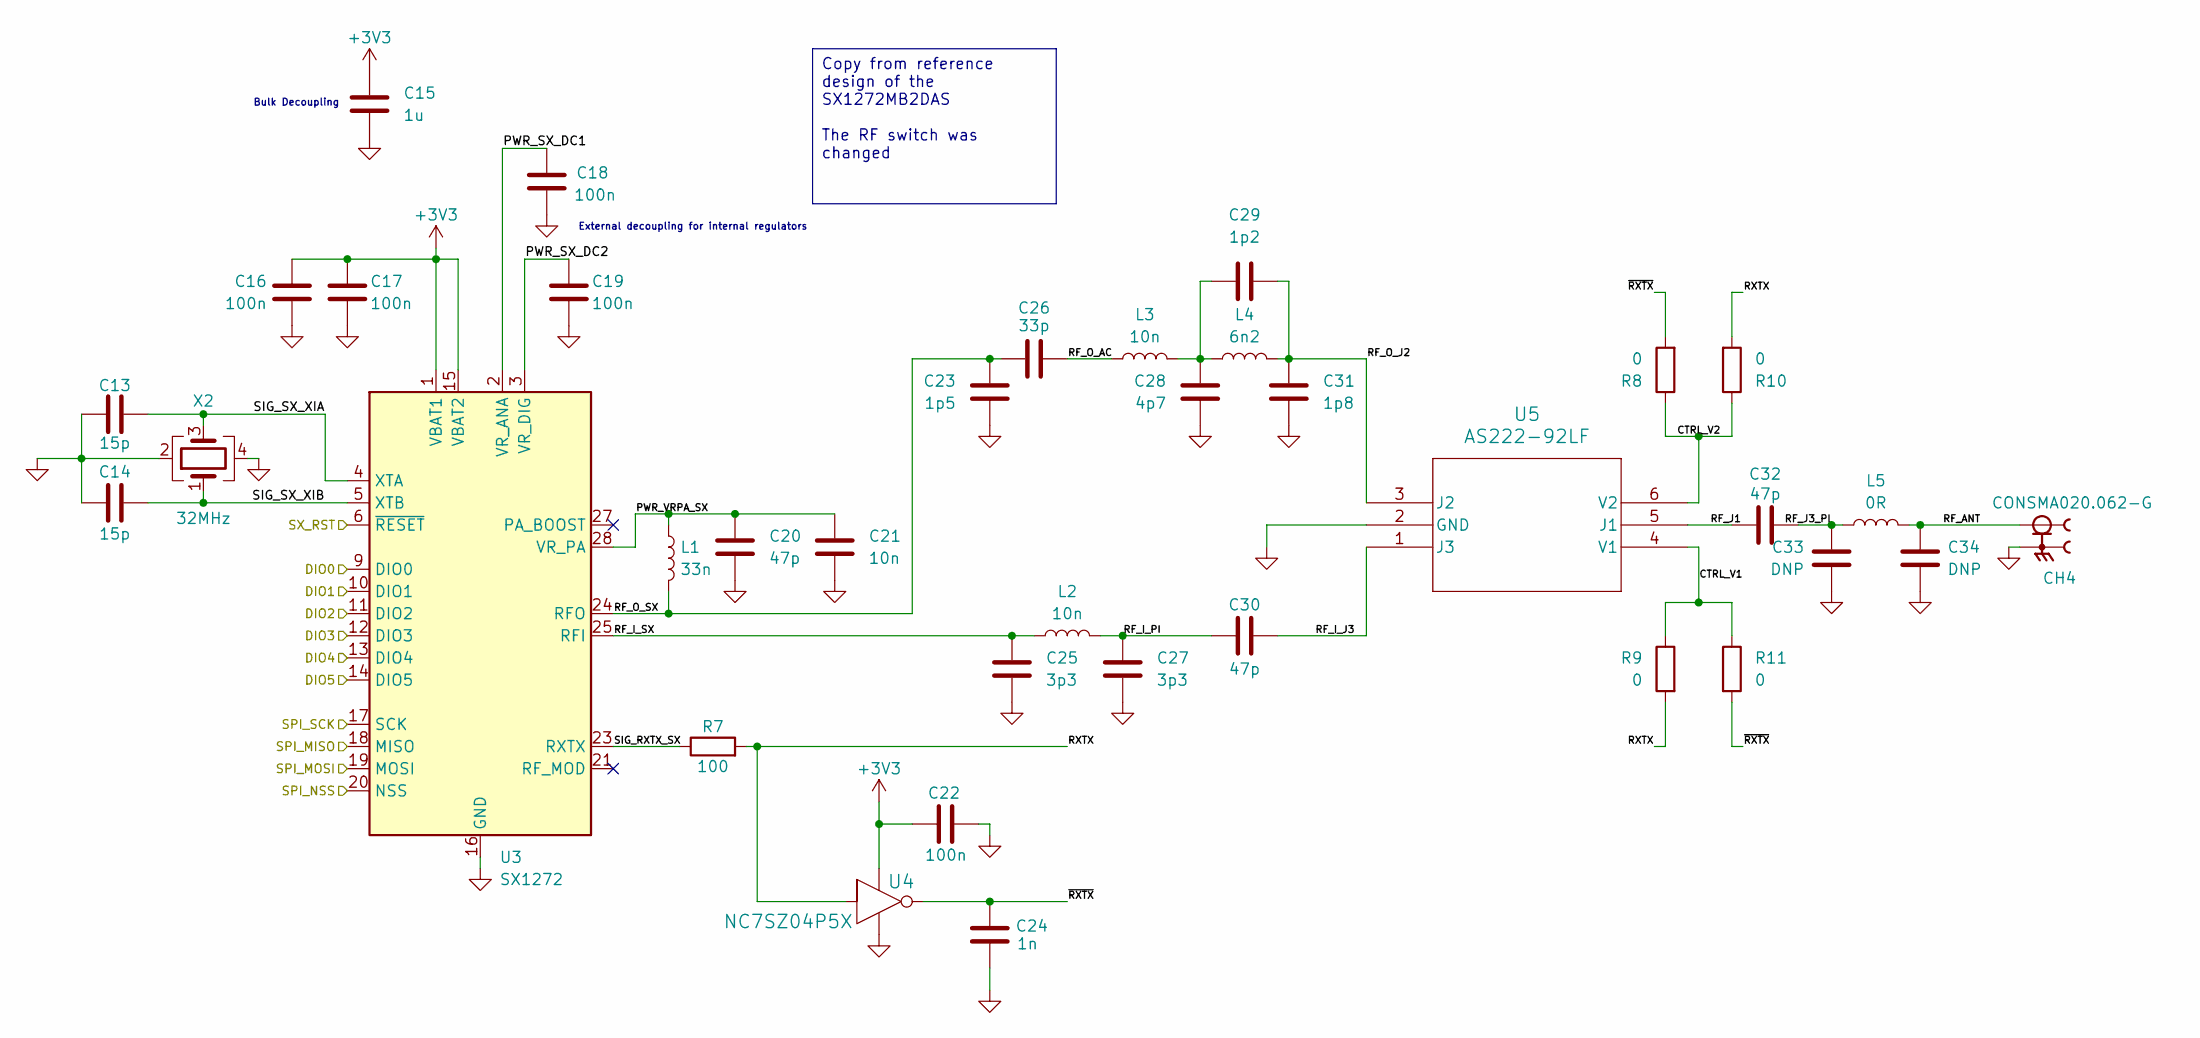
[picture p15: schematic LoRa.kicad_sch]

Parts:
C13, C14: 15p; C_0402_1005Metric
C15: 1u; C_0402_1005Metric
C16, C17, C18, C19, C22: 100n; C_0402_1005Metric
C20, C30, C32: 47p; C_0402_1005Metric
C21: 10n; C_0402_1005Metric
C23: 1p5; C_0402_1005Metric
C24: 1n; C_0402_1005Metric
C25, C27: 3p3; C_0402_1005Metric
C26: 33p; C_0402_1005Metric
C28: 4p7; C_0402_1005Metric
C29: 1p2; C_0402_1005Metric
C31: 1p8; C_0402_1005Metric
C33, C34: DNP; C_0402_1005Metric
CH4: CONSMA020.062-G; LINX_CONSMA020.062-G
L1: 33n; L_0402_1005Metric
L2, L3: 10n; L_0402_1005Metric
L4: 6n2; L_0402_1005Metric
L5: 0R; L_0402_1005Metric
R7: 100; R_0402_1005Metric
R8, R9, R10, R11: 0; R_0402_1005Metric
U3: SX1272; QFN-28-1EP_6x6mm_P0.65mm_EP4.8x4.8mm
U4: NC7SZ04P5X; SC-88A-5_1P35X2P2_ONS
U5: AS222-92LF; SC-70-6_PSM
X2: 32MHz; Crystal_SMD_2016-4Pin_2.0x1.6mm

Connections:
+3V3: C15.1, C16.1, C17.1, C22.1, U3.1 (VBAT1), U3.15 (VBAT2), U4.5; also elsewhere on the board
/LoRa/CTRL_V1: R9.1, R11.1, U5.4 (V1)
/LoRa/CTRL_V2: R8.1, R10.1, U5.6 (V2)
/LoRa/PWR_SX_DC1: C18.1, U3.2 (VR_ANA)
/LoRa/PWR_SX_DC2: C19.1, U3.3 (VR_DIG)
/LoRa/PWR_VRPA_SX: C20.1, C21.1, L1.1, U3.28 (VR_PA)
/LoRa/RF_ANT: C34.2, CH4.1, L5.2
/LoRa/RF_I_J3: C30.2, U5.1 (J3)
/LoRa/RF_I_PI: C27.1, C30.1, L2.2
/LoRa/RF_I_SX: C25.1, L2.1, U3.25 (RFI)
/LoRa/RF_J1: C32.1, U5.5 (J1)
/LoRa/RF_J3_PI: C32.2, C33.2, L5.1
/LoRa/RF_O_AC: C26.2, L3.1
/LoRa/RF_O_J2: C29.2, C31.2, L4.2, U5.3 (J2)
/LoRa/RF_O_SX: C23.1, C26.1, L1.2, U3.24 (RFO)
/LoRa/RXTX: R7.2, R9.2, R10.2, U4.2
/LoRa/SIG_RXTX_SX: R7.1, U3.23 (RXTX)
/LoRa/SIG_SX_XIA: C13.1, U3.4 (XTA), X2.3
/LoRa/SIG_SX_XIB: C14.1, U3.5 (XTB), X2.1
/LoRa/~RXTX: C24.1, R8.2, R11.2, U4.4
/SPI1_MISO: U3.18 (MISO); also elsewhere on the board
/SPI1_MOSI: U3.19 (MOSI); also elsewhere on the board
/SPI1_NSS: U3.20 (NSS); also elsewhere on the board
/SPI1_SCK: U3.17 (SCK); also elsewhere on the board
/SX_DIO0: U3.9 (DIO0); also elsewhere on the board
/SX_DIO1: U3.10 (DIO1); also elsewhere on the board
/SX_DIO2: U3.11 (DIO2); also elsewhere on the board
/SX_DIO3: U3.12 (DIO3); also elsewhere on the board
/SX_DIO4: U3.13 (DIO4); also elsewhere on the board
/SX_DIO5: U3.14 (DIO5); also elsewhere on the board
/SX_RST: U3.6 (~RESET); also elsewhere on the board
GND: C13.2, C14.2, C15.2, C16.2, C17.2, C18.2, C19.2, C20.2, C21.2, C22.2, C23.2, C24.2, C25.2, C27.2, C28.1, C31.1, C33.1, C34.1, CH4.S1, CH4.S2, CH4.S3, CH4.S4, U3.16 (GND), U3.22 (GND), U3.26 (GND), U3.29 (GND), U4.3, U5.2 (GND), X2.2, X2.4; also elsewhere on the board
unnamed: C28.2, C29.1, L3.2, L4.1

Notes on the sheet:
Bulk Decoupling
External decoupling for internal regulators
Copy from reference design of the SX1272MB2DAS The RF switch was changed

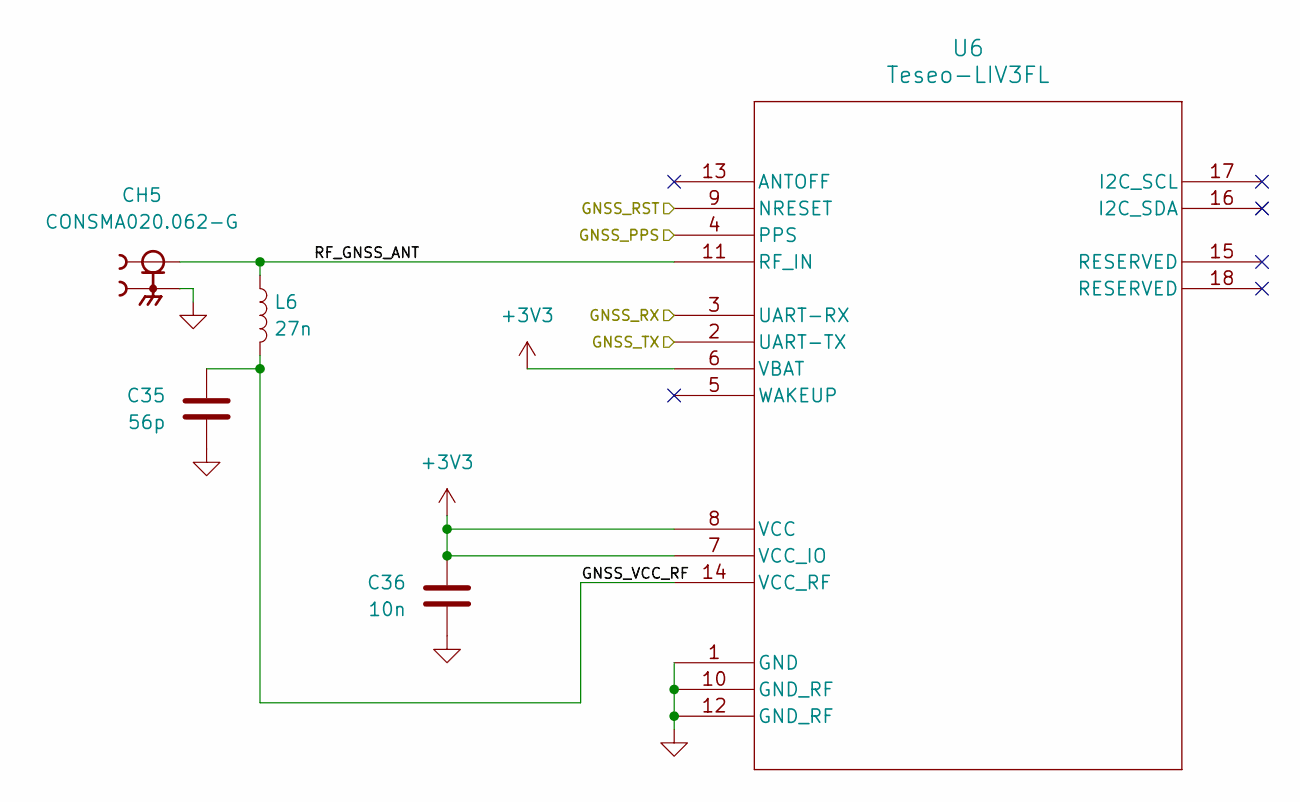
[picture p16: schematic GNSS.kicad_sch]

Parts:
C35: 56p; C_0402_1005Metric
C36: 10n; C_0402_1005Metric
CH5: CONSMA020.062-G; LINX_CONSMA020.062-G
L6: 27n; L_0402_1005Metric
U6: Teseo-LIV3FL; LIV3FL_STM

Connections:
+3V3: C36.1, U6.6 (VBAT), U6.7 (VCC_IO), U6.8 (VCC); also elsewhere on the board
/GNSS/GNSS_VCC_RF: C35.1, L6.2, U6.14 (VCC_RF)
/GNSS/RF_GNSS_ANT: CH5.1, L6.1, U6.11 (RF_IN)
/GPIO_GNSS_RST: U6.9 (NRESET); also elsewhere on the board
/GPIO_PPS: U6.4 (PPS); also elsewhere on the board
/UART4_RX: U6.2 (UART-TX); also elsewhere on the board
/UART4_TX: U6.3 (UART-RX); also elsewhere on the board
GND: C35.2, C36.2, CH5.S1, CH5.S2, CH5.S3, CH5.S4, U6.1 (GND), U6.10 (GND_RF), U6.12 (GND_RF); also elsewhere on the board

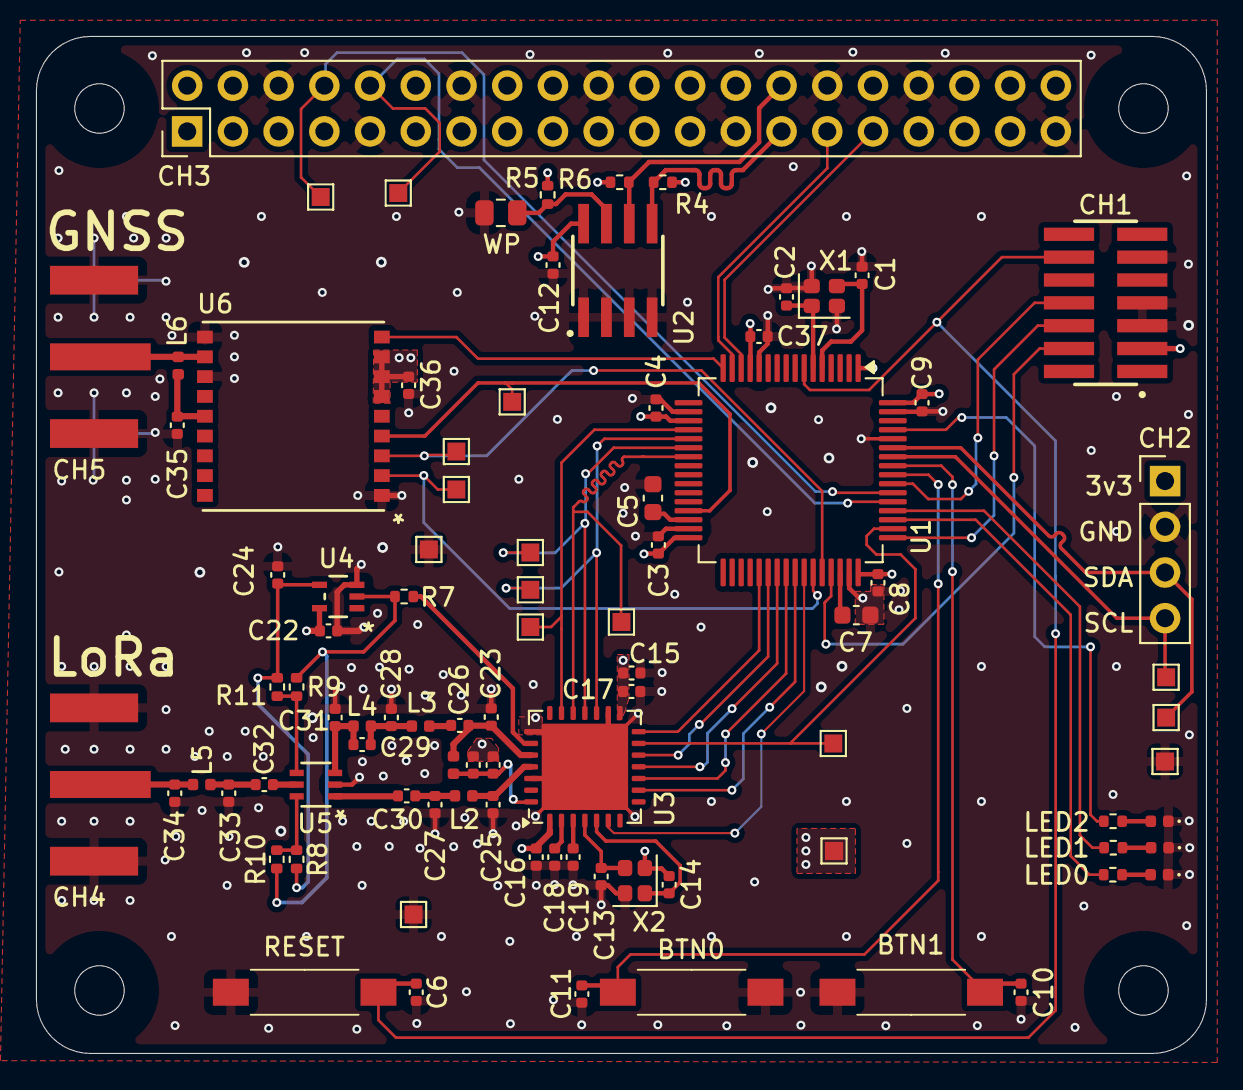
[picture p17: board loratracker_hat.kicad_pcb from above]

Board: 4 copper layers, 65.0 x 56.5 mm, 94 parts (0 on the bottom side), 64 nets.

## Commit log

2025-09-02 LoRa Tracker HAT+ v1.0
    [GNSS.kicad_sch, LoRa.kicad_sch, RPi.kicad_sch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]
2025-09-02 update output files for v1.0
    [GNSS.kicad_sch, LoRa.kicad_sch, RPi.kicad_sch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]
